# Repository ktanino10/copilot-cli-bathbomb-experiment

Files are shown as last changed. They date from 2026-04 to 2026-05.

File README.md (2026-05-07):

# 🛁🐱 copilot-cli-bathbomb-experiment

**[日本語](#日本語) | [English](#english)**

---

## 日本語

🧪 GitHub Copilot CLIで画像からバスボム用3Dプリント型（モールド）を自動生成する実験記録

### 概要

GitHub のロゴ（Octocat）の画像から、猫型バスボム用の3Dプリント型を自動生成します。
2分割のクラムシェル（貝殻型）構造で、乾燥後に左右にパカッと開いてバスボムを取り出せます。

### 生成される型

猫シルエットの **クラムシェル2分割型**（左右ハーフ：A・B）

- 左右ハーフが鏡像でパーティングプレーン上で合わさる
- 抜き勾配 **8°**（v1の5°から増、粉末材料での離型性を改善）
- フィレット R3mm（角を丸めてひび割れ防止）
- 壁厚 4mm・床厚 4mm
- 外周フランジ 5mm 幅（ゴムバンドで圧着するためのリム）
- φ4mm 位置決めピン × 4 本（ハーフAにピン、ハーフBに穴）
- 目標サイズ：おおむね 80×80×20mm の手のひらサイズバスボム

### 過去の試作（参考）

第1回試作の片面コンテナ型 (`mold_cat_container.stl` / `mold_cat_container_mirrored.stl`) は履歴として残しています。失敗の経緯は [`experiments/2026-05-04-trial-01/`](experiments/2026-05-04-trial-01/) を参照。

### 🎉 成功事例（Trial 02）

第2回試作で **4色のOctocat バスボム作りに成功** しました 🐱✨
GitHub を退職する同僚（元 Microsoft 社員）への餞別ギフトとして、Microsoft ロゴカラー（赤・緑・青・黄）の 4 色 Octocat バスボムを製作し、**Lush で買った期間限定の「マリオはてなブロック」型ギフトボックス**に詰めて贈りました（ついでに同店で「ヨッシーの卵」バスボム＋泡ボムも購入し、保険として同梱）。

ちなみに今回は v2 自動生成クラムシェルを **使わず**、v1 のコンテナ型を **Bambu Studio で左右 2 分割** にカットして印刷した workaround で離型問題を解決しています。

| 離型成功 | 4 色セット完成 |
|---|---|
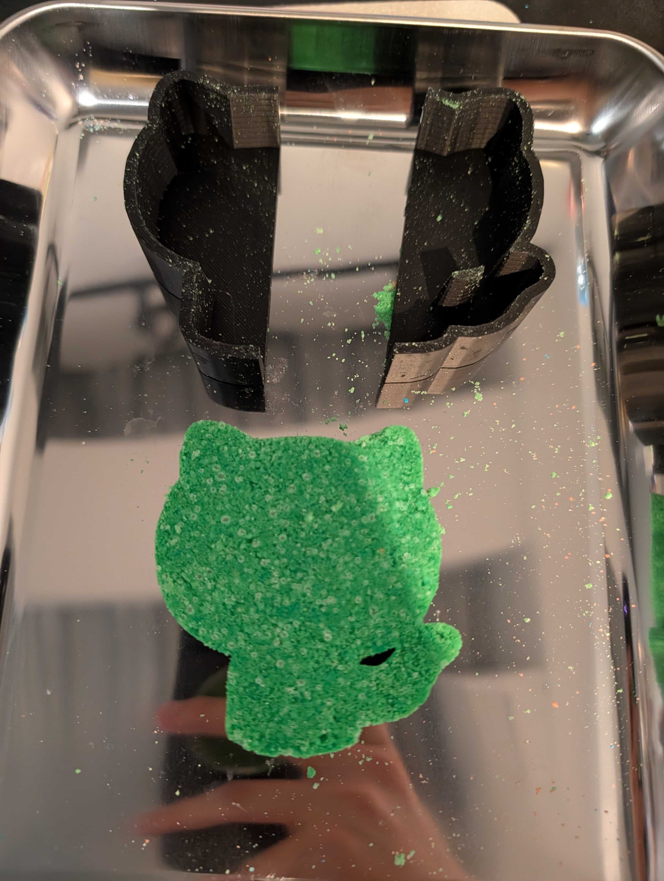
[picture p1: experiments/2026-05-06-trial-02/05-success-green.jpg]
成功した緑バスボム
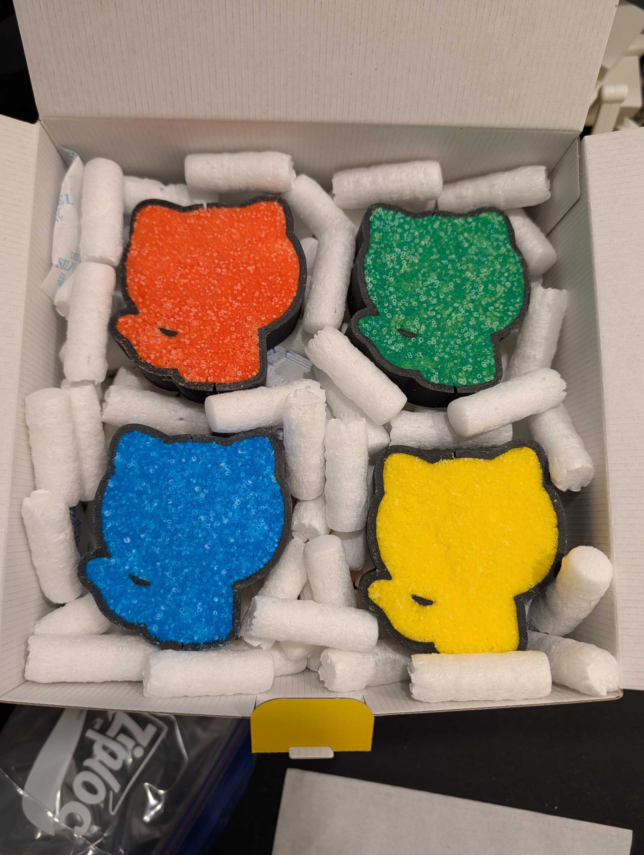
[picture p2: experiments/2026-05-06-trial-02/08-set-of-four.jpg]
4色Octocatバスボム
|  |  |

詳しい製作工程・レシピ・写真・動画・学びは [`experiments/2026-05-06-trial-02/`](experiments/2026-05-06-trial-02/) を参照。

> 📘 **離型ガイド (GitHub Pages)**: 完成したバスボムを型から崩さずに取り出すコツを
> Codelab 形式でまとめています →
> **<https://ktanino10.github.io/copilot-cli-bathbomb-experiment/>**
> （8 ステップ・約 14 分。NG 動作／推奨手順／"そもそも完全に外さない" 運用 ほか）
> 🌐 **日本語 / English** 両対応 — 右上のセレクターで切り替え可
> ([🇯🇵 JA](https://ktanino10.github.io/copilot-cli-bathbomb-experiment/?version=v1.0.0&lang=ja) ·
>  [🇬🇧 EN](https://ktanino10.github.io/copilot-cli-bathbomb-experiment/?version=v1.0.0&lang=en))

### 使い方

```bash
# 依存ライブラリのインストール
pip install pillow numpy scipy scikit-image shapely trimesh manifold3d

# STLファイル生成
python generate_mold.py
```

### 出力ファイル

```
mold_cat_clamshell_A.stl  — クラムシェル ハーフA（位置決めピン付き）
mold_cat_clamshell_B.stl  — クラムシェル ハーフB（ピン穴付き）
```

両方を1部ずつプリントして1セットになります。

### 📸 STL プレビュー

> ⚠️ **GitHub の STL 3D ビューアが「Unable to render code block」と表示されることがあります。**
> 形を確認するための静的プレビュー画像を `previews/` に同梱しています。
> 詳細にスクスクと回したい場合は、STL を [Raw でダウンロード](https://raw.githubusercontent.com/ktanino10/copilot-cli-bathbomb-experiment/main/mold_cat_clamshell_A.stl) して
> [ViewSTL](https://www.viewstl.com/) などのオンラインビューアで開くか、Bambu Studio などローカルツールでご覧ください。

| クラムシェル A（v2、ピン付き） | クラムシェル B（v2、穴付き） |
|---|---|
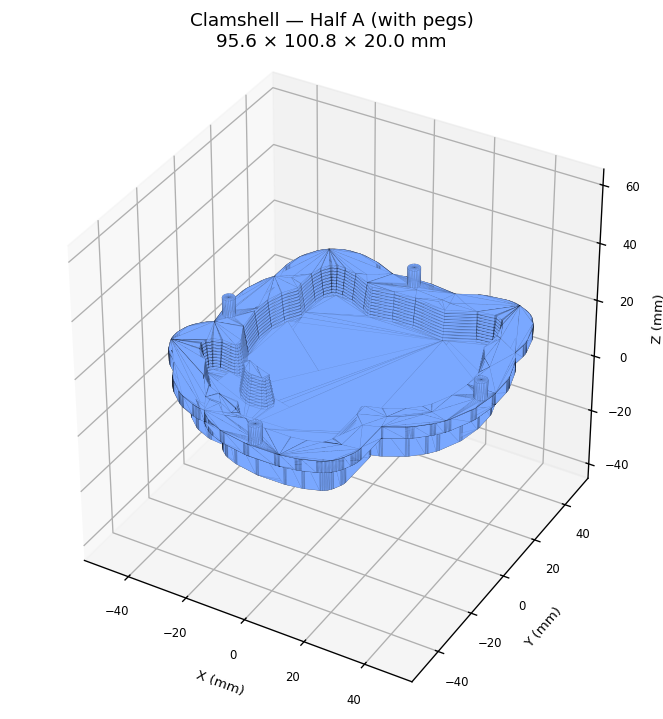
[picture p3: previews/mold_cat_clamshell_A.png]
Half A preview
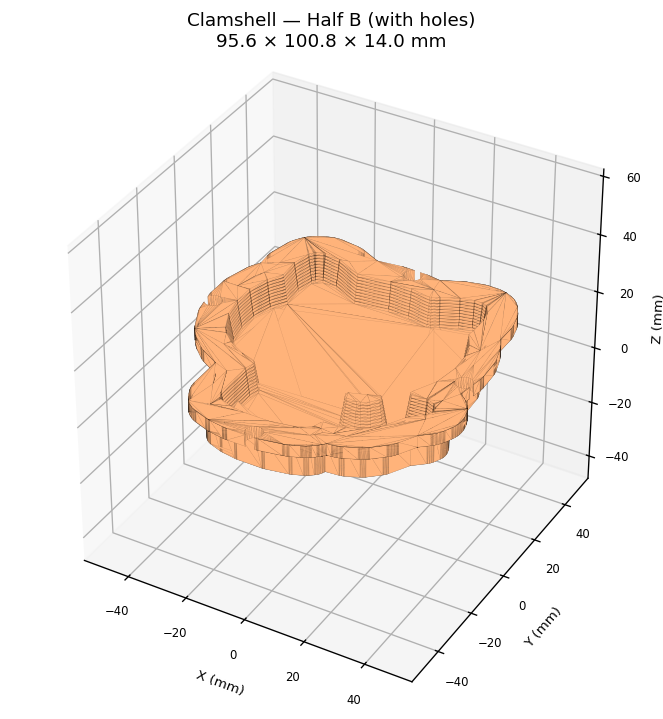
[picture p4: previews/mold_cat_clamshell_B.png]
Half B preview
|  |  |

| v1 コンテナ型（参考） | v1 コンテナ型・ミラー（参考） |
|---|---|
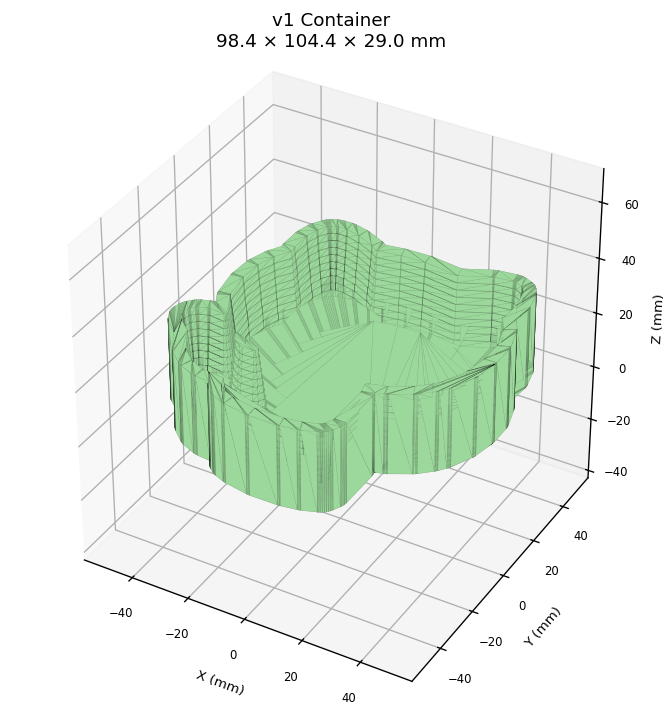
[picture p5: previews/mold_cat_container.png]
v1 preview
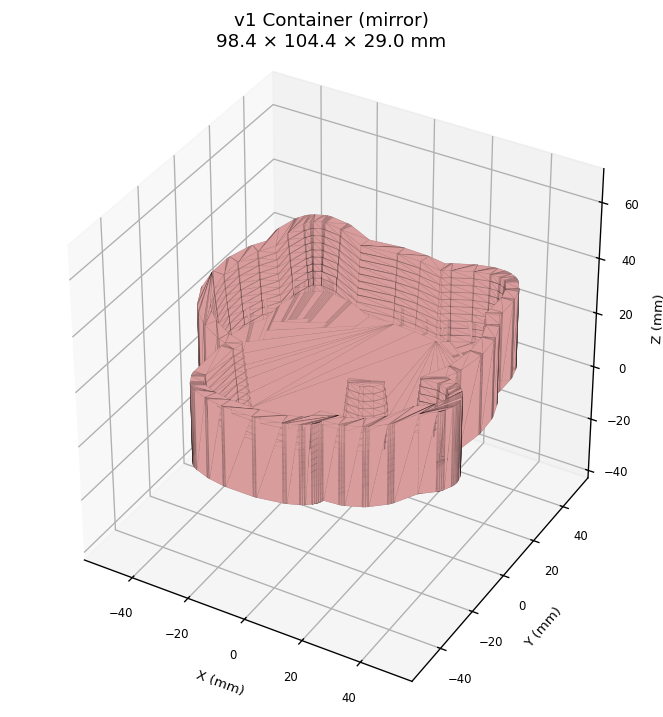
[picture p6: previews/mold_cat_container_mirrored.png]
v1 mirrored preview
|  |  |

これらの PNG は `python generate_previews.py` で再生成できます（trimesh + matplotlib）。

### 3Dプリント推奨設定

| パラメータ | 設定値 |
|---|---|
| プリンター | FDM |
| フィラメント | PLA |
| レイヤー高さ | 0.2mm |
| インフィル | 20〜30% |
| サポート | なし |
| ブリム | あり（反り防止） |

印刷後はキャビティ内面をサンドペーパー（#400→#800）で研磨し、使用時は食品用ラップを敷いてください。

### 型の設計仕様

| 項目 | 値 |
|---|-----|
| 構造 | クラムシェル2分割（左右ハーフ） |
| キャビティ深さ | 10mm × 2（合計約20mm） |
| 猫シルエット幅 | 約80mm |
| 壁厚 | 4mm |
| 床厚 | 4mm |
| 抜き勾配 | 8° |
| フィレット | R3mm |
| フランジ幅 / 厚さ | 5mm / 4mm |
| 位置決めピン | φ4mm × 4本（A：ピン／B：穴） |

### 制作ガイド

📖 **[GUIDE.md](GUIDE.md)** — 買い出しリスト・全手順・トラブルシューティング（日本語）

📖 **[GUIDE_EN.md](GUIDE_EN.md)** — Full guide in English

### ツール

- [GitHub Copilot CLI](https://githubnext.com/projects/copilot-cli/)
- Python 3 + trimesh + manifold3d（3Dブーリアン演算）
- scikit-image + shapely（画像→ポリゴン変換）

---

## English

🧪 Experiment: Auto-generating 3D-printable bath bomb molds from images with GitHub Copilot CLI

### Overview

Automatically generates a 3D-printable bath bomb mold in the shape of the GitHub Octocat,
designed as a **two-piece clamshell** so the finished bath bomb pops out cleanly when the
two halves are unclipped after drying.

### Generated Mold

Two-piece **clamshell** mold (halves A and B):

- Mirrored halves meeting on a flat parting plane
- **8° draft angle** (steeper than v1's 5° — much easier release for powdery material)
- R3mm fillets on the cat silhouette (prevents cracking)
- 4mm walls and 4mm floor on each half
- 5mm outer flange around the parting plane (for rubber-band clamping)
- 4 × φ4mm alignment dowels (pegs on side A, matching holes on side B)
- Target bath bomb size ≈ 80×80×20mm — fits in one hand

### Previous Trial (kept for reference)

The original single-sided container mold (`mold_cat_container.stl` /
`mold_cat_container_mirrored.stl`) is kept in the repo as historical artifact.
See [`experiments/2026-05-04-trial-01/`](experiments/2026-05-04-trial-01/) for what went wrong.

### 🎉 Success Story (Trial 02)

The second trial **produced four Octocat bath bombs successfully** 🐱✨
They were made as a farewell gift for a colleague leaving GitHub (formerly at Microsoft) — cast in
the **Microsoft logo colors (red, green, blue, yellow)** and packed into a
**Mario "question-block" gift box bought at Lush as a limited-edition item**
(a Lush "Yoshi's Egg" bath bomb and a foam bomb were picked up at the same store
and included as backup gifts).

Note that this batch did **not** use the v2 auto-generated clamshell; instead the v1 container
mold was **split left/right in Bambu Studio's slicer** before printing — a workaround that
solved the demolding problem with no model redesign.

| Clean release | Four-color set |
|---|---|
| Successful green Octocat | Four Octocat bath bombs |

See [`experiments/2026-05-06-trial-02/`](experiments/2026-05-06-trial-02/) for the full
process, recipe, photos, video and lessons learned.

> 📘 **Demolding Guide (GitHub Pages)**: a Codelab-style walkthrough of how to
> safely release the finished bath bomb from its mold →
> **<https://ktanino10.github.io/copilot-cli-bathbomb-experiment/>**
> (8 steps · ~14 min · do's and don'ts, the recommended one-half release,
> and the "don't fully demold at all" gifting pattern).
> 🌐 **Available in 日本語 / English** — toggle in the top-right
> ([🇬🇧 EN](https://ktanino10.github.io/copilot-cli-bathbomb-experiment/?version=v1.0.0&lang=en) ·
>  [🇯🇵 JA](https://ktanino10.github.io/copilot-cli-bathbomb-experiment/?version=v1.0.0&lang=ja))

### Usage

```bash
# Install dependencies
pip install pillow numpy scipy scikit-image shapely trimesh manifold3d

# Generate STL
python generate_mold.py
```

### Output

```
mold_cat_clamshell_A.stl  — Clamshell half A (with alignment pegs)
mold_cat_clamshell_B.stl  — Clamshell half B (with matching holes)
```

Print one of each to make a complete set.

### 📸 STL Previews

> ⚠️ **GitHub's inline STL 3D viewer sometimes shows "Unable to render code block".**
> Static PNG previews are included in `previews/` so you can see the geometry
> without the viewer. For an interactive look, download the raw STL and open it
> in [ViewSTL](https://www.viewstl.com/) or a local tool like Bambu Studio /
> PrusaSlicer / MeshLab.

| Clamshell A (v2, with pegs) | Clamshell B (v2, with holes) |
|---|---|
| Half A preview | Half B preview |

| v1 container (reference) | v1 container, mirrored (reference) |
|---|---|
| v1 preview | v1 mirrored preview |

These PNGs are regenerated by `python generate_previews.py` (trimesh + matplotlib).

### Recommended Print Settings

| Parameter | Value |
|---|---|
| Printer | FDM |
| Filament | PLA |
| Layer height | 0.2mm |
| Infill | 20–30% |
| Support | None |
| Brim | Yes (prevents warping) |

Sand the cavity interior (#400 → #800 grit) after printing. Line with plastic wrap before use.

### Mold Specs

| Spec | Value |
|---|---|
| Structure | Two-piece clamshell (halves A + B) |
| Cavity depth | 10mm × 2 (≈20mm total bath bomb) |
| Cat silhouette width | ≈80mm |
| Wall thickness | 4mm |
| Floor thickness | 4mm |
| Draft angle | 8° |
| Fillet radius | R3mm |
| Flange width / thickness | 5mm / 4mm |
| Alignment dowels | 4 × φ4mm (pegs on A, holes on B) |

### Crafting Guide

📖 **[GUIDE.md](GUIDE.md)** — Full guide in Japanese (日本語)

📖 **[GUIDE_EN.md](GUIDE_EN.md)** — Shopping list, step-by-step instructions & troubleshooting

### Tools

- [GitHub Copilot CLI](https://githubnext.com/projects/copilot-cli/)
- Python 3 + trimesh + manifold3d (3D boolean operations)
- scikit-image + shapely (image → polygon conversion)

## License

MIT

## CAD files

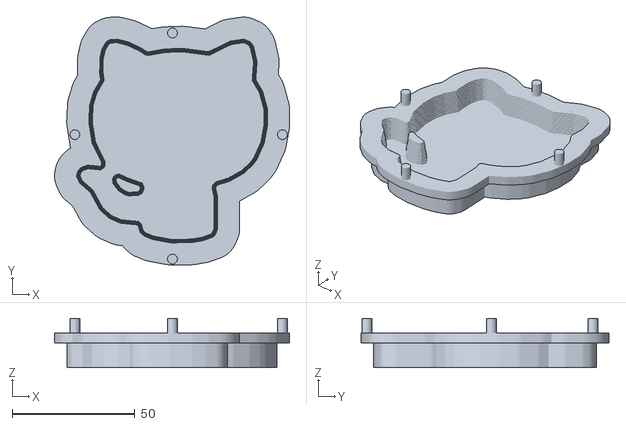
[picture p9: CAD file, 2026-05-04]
mold_cat_clamshell_A.stl
95.6 x 100.8 x 20.0

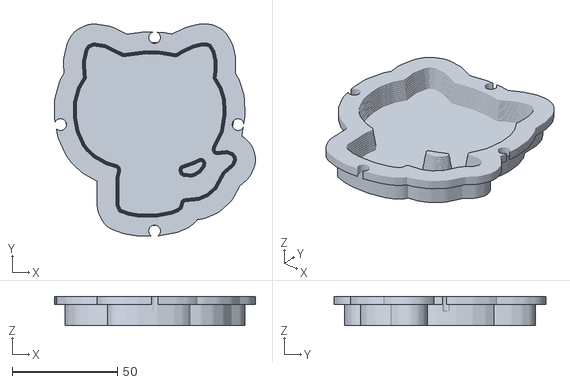
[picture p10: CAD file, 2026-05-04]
mold_cat_clamshell_B.stl
95.6 x 100.8 x 14.0

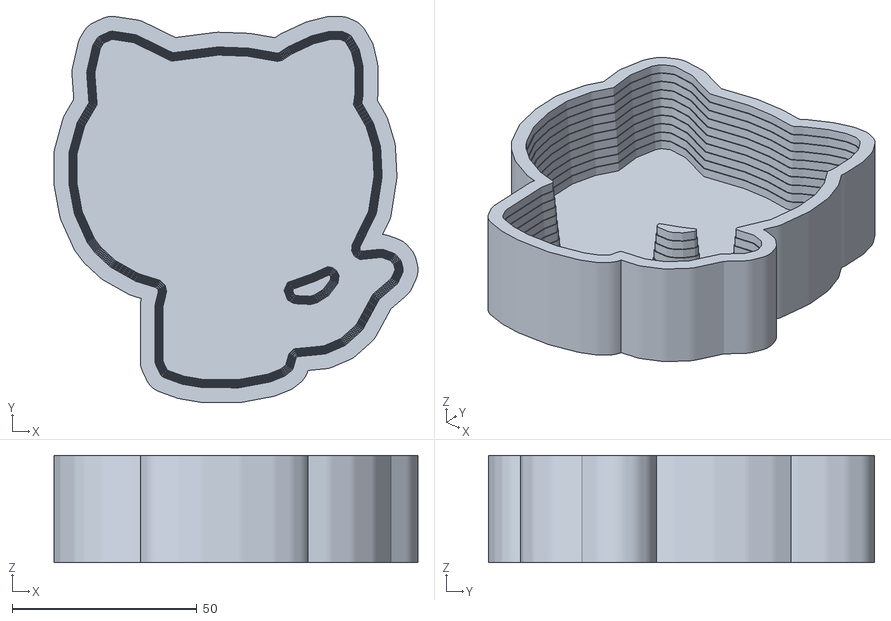
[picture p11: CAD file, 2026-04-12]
mold_cat_container_mirrored.stl
98.4 x 104.4 x 29.0

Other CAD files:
mold_cat_container.stl

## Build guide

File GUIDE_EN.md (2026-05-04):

# 🛁🐱 GitHub Octocat Bath Bomb — Complete Crafting Guide

A black, lavender-scented bath bomb shaped like the GitHub Octocat.
The **two-piece clamshell mold** holds the shape firmly while it cures, then
opens like a shell so the bath bomb pops out cleanly.

---

## 📋 Shopping List

### 🛒 Grocery / Dollar Store
| # | Item | Purpose | Notes |
|---|---|---|---|
| 1 | Baking soda (food grade) | Main ingredient | 200g+ |
| 2 | Citric acid | Fizzing agent | 100g+ |
| 3 | Cornstarch | Binding agent | 50g |
| 4 | Small spray bottle | For spraying rubbing alcohol | ~50ml |
| 5 | Rubber gloves | Prevent charcoal stains | Disposable |
| 6 | Thick rubber bands or hair ties | Clamp the two halves together | 2–3 pieces |
| 7 | Clear gift bags | Gift wrapping | With ribbon if possible |

### 💊 Pharmacy / Drugstore
| # | Item | Purpose | Notes |
|---|---|---|---|
| 8 | Isopropyl alcohol (91%+) or witch hazel | Moistening agent (water substitute) | ~$5. Water triggers fizzing — must use alcohol! |

### 🛍 Grocery Store
| # | Item | Purpose | Notes |
|---|---|---|---|
| 9 | Coconut oil or olive oil | Moisturizer / binder | 1–2 tbsp needed |

### 📦 Online (order in advance)
| # | Item | Purpose | Notes |
|---|---|---|---|
| 10 | Lavender essential oil | Fragrance | 10ml bottle |
| 11 | Activated charcoal powder (food grade) | Black color | 1–2 tsp needed |

### 🏠 Already at Home (check)
| Item | Purpose |
|---|---|
| Large bowl | Mixing |
| Measuring spoons / kitchen scale | Measuring |
| Plastic wrap or cooking oil (release agent) | Line / coat the cavity for easy demold |
| Parchment paper | Drying surface |
| Spatula or ruler | Smooth the surface |
| Sandpaper #400, #800 | Smooth the 3D-printed mold interior |

### 💰 Estimated Budget: $15–30

---

## 🗓 Schedule Overview

| Phase | Task | Time |
|---|---|---|
| **A. 3D Print** | Print one of each STL (halves A and B) | 2–3 hours |
| **B. Shopping** | Buy materials (parallel with A) | — |
| **C. Mold Prep** | Sand interior + flatten flange | 20 min |
| **D. Crafting** | Mix → fill halves → close clamshell | 1–1.5 hours |
| **E. Drying** | Let sit clamped | 24–48 hours |
| **F. Finishing** | Open clamshell → demold → wrap | 30 min |

---

## 🔧 Phase A: 3D Printing

### Slicer Settings (Cura, etc.)
| Parameter | Value |
|---|---|
| Files | `mold_cat_clamshell_A.stl` + `mold_cat_clamshell_B.stl` |
| Filament | PLA |
| Layer height | 0.2mm |
| Infill | 20–30% |
| Wall thickness | 1.2mm (3 walls) |
| Support | **None** |
| Brim | **Yes** (prevents warping) |
| Nozzle temp | 200–210°C |
| Bed temp | 60°C |

💡 **Print orientation tip**: Print each half with the **flange face up** (cavity-back side on the bed). This keeps the pin/hole geometry crisp and the flange flat for a tight seal.

### After Printing
1. Remove brim with a knife
2. Sand the cavity interior:
   - **#400 grit** → remove layer lines
   - **#800 grit** → smooth finish
3. Lightly sand the **flange face** with #400 to ensure it's perfectly flat (better seal)
4. Test-fit the two halves: pegs should slide into holes with a snug press fit

---

## 🧪 Phase D: Making the Bath Bomb

### D-1. Mix Dry Ingredients
```
Add to bowl in order:
  ① Baking soda       200g
  ② Citric acid        100g
  ③ Cornstarch          50g
  ④ Charcoal powder     1–2 tsp (start small!)
```
- Wear rubber gloves! (charcoal stains are hard to remove)
- Mix thoroughly with a fork, breaking up any clumps (2–3 min)

### D-2. Add Wet Ingredients
```
  ⑤ Coconut oil        1–2 tbsp (melt in microwave if solid)
  ⑥ Lavender EO        10–15 drops
```
- Mix well

### D-3. Adjust Moisture
```
  ⑦ Pour rubbing alcohol into spray bottle
    → Spritz 1–2 pumps at a time while mixing
```
- 🎯 **Target consistency**: Holds shape when squeezed, crumbles when lightly pressed
  - Like "wet sand" texture
  - Too crumbly → one more spritz
  - Too wet → add a little baking soda

- ⚠️ **NEVER use water!** It triggers the fizzing reaction

### D-4. Fill the Clamshell Mold

```
   Half A (pin side)         Half B (hole side)
   ┌─────────────────┐       ┌─────────────────┐
   │  ① Coat cavity   │       │  ① Coat cavity   │   ← thin smear of oil
   │     with oil     │       │     with oil     │     (or line with wrap)
   │                  │       │                  │
   │  ② Heap mixture  │       │  ② Heap mixture  │   ← slightly above
   │     in cavity ↑↑↑│       │     in cavity ↑↑↑│     the cavity rim
   │                  │       │                  │
   │  ③ Pack firmly   │       │  ③ Pack firmly   │
   └─────────────────┘       └─────────────────┘
                  ↓ clamp ↓
            ┌─────────────────┐
            │ Press the two    │  ← align pins into holes
            │ halves together  │     and push straight down
            │ (the heaped mix  │
            │  compresses for  │
            │  a tight bond)   │
            └─────────────────┘
                  ↓ secure ↓
            ┌─────────────────┐
            │  ④ Wrap rubber   │  ← cross-pattern (X) over
            │     bands tightly│     the flange
            └─────────────────┘
```

#### Detailed Steps:
1. **Coat the cavity**: Smear a thin layer of cooking oil (or coconut oil) on the interior of each half with a finger or paper towel. (Better than plastic wrap for a clamshell — wrap tends to wrinkle in this geometry.)
2. **Fill both halves**: Divide the mixture roughly in half and **heap it slightly above the rim** of each cavity (the excess will compress when you close the clamshell).
3. **Pack firmly**: Press the mixture in each half with your fingertips.
4. **Close the clamshell**: Place half B (holes) onto half A (pins), aligning the pegs into the holes. Press straight down firmly until the flanges meet.
5. **Clamp with rubber bands**: Wrap rubber bands across the flange in an X pattern (one vertical, one horizontal). They must be tight — slack means a gap and a visible seam.

---

## ⏳ Phase E: Drying

1. Leave the clamped clamshell on parchment paper
2. Place in a **well-ventilated area** for **24–48 hours**
3. ⚠️ **Don't touch it!** It's extremely fragile while drying
4. ⚠️ Avoid humid areas (bathroom, kitchen)
5. Summer: 24 hours. Winter: 48 hours.

---

## 🎁 Phase F: Finishing & Wrapping

### Opening the Clamshell
1. Carefully remove the rubber bands
2. Hold the flange with both hands and **gently pull the two halves apart** sideways (like opening a clam)
3. The bath bomb usually stays in one half — flip that half over and **let it drop into your palm**
4. If it sticks, **tap the back of the half lightly** with your other hand
5. ⚠️ Be gentle — ears and tentacle are fragile

### Touch-up
- A faint flash line may appear along the parting plane — smooth it with a finger
- If a corner chipped, press leftover mixture onto it to repair

### Gift Wrapping
1. Wrap the bath bomb tightly in plastic wrap (moisture barrier)
2. Place in a clear gift bag with a ribbon
3. Include a usage card (see below)

### Usage Card (to include with gift)
```
┌──────────────────────────────────────┐
│  🛁 GitHub Octocat Bath Bomb         │
│                                      │
│  Drop into a warm bath (38–40°C)     │
│  and watch it fizz, releasing        │
│  a relaxing lavender scent.          │
│                                      │
│  ⚠️ The water will turn dark —       │
│  activated charcoal is natural       │
│  and gentle on skin.                 │
│                                      │
│  🌿 Enjoy the lavender scent!        │
└──────────────────────────────────────┘
```

---

## ⚠️ Troubleshooting

| Problem | Cause | Fix |
|---|---|-----|
| Won't hold shape / crumbly | Not enough alcohol | Add 1–2 more spritzes |
| Started fizzing during mixing | Water got in | Mold quickly. Next time use only alcohol |
| Won't release from cavity | Forgot release agent / packed too tight | Always coat with oil. Try 30 min in freezer |
| Clamshell won't close | Too much mixture in the halves | Heap less — just enough to compress on close |
| Visible seam / gap at parting line | Rubber bands too loose | Use stronger bands in a tight X pattern |
| Ears broke off | Thin sections are fragile | Repair with leftover mixture. Pack thicker next time |
| Cracked while drying | Dried too fast / uneven thickness | Move to a less drafty spot; the closed mold dries it slowly which is good |
| Water turned pitch black | Too much charcoal | Use ½ tsp next time |
| Bathtub stained | Charcoal / food coloring | Clean with melamine sponge. Charcoal stains less |

---

## 💡 Tips for Success

1. **Practice first**: Make a small round bath bomb by hand to get the feel
2. **Charcoal — less is more**: ½ tsp is enough for deep black. Too much = pitch-black bath water
3. **Release agent — go thin**: Too much oil makes the bath bomb surface greasy
4. **Pack firmly**: Harder than you think. Weak packing = crumbling
5. **Alcohol — go slow**: Too little is better than too much
6. **Store sealed**: Keep finished bath bomb away from moisture. Gift within 1–2 weeks

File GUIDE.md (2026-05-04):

# 🛁🐱 GitHub Octocat バスボム — 完全制作ガイド

黒色・ラベンダーの香り付きの猫型バスボム。
**クラムシェル2分割型**でしっかりした形を成形し、乾燥後はパカッと開いて取り出します。

---

## 📋 買い出しリスト

### 🛒 100均（ダイソー・セリア等）
| # | 商品 | 用途 | 備考 |
|---|---|---|---|
| 1 | 重曹（食用グレード） | バスボム主成分 | 200g以上。掃除用でも可だが食用が肌に優しい |
| 2 | クエン酸 | 発泡剤 | 100g以上 |
| 3 | 片栗粉 or コーンスターチ | 固め剤 | 50g |
| 4 | スプレーボトル（小） | エタノール噴霧用 | 50ml程度 |
| 5 | ゴム手袋 | 竹炭で手が汚れるのを防止 | 使い捨てタイプ |
| 6 | 輪ゴム（太め）or ヘアゴム | 型を圧着するため | 2〜3本 |
| 7 | ラッピング袋（透明） | ギフト包装 | リボン付きだと便利 |

### 💊 ドラッグストア
| # | 商品 | 用途 | 備考 |
|---|---|---|---|
| 8 | 無水エタノール | 湿らせ用（水の代替） | ¥400〜600。水だと発泡が始まるため必須 |

### 🛍 スーパー
| # | 商品 | 用途 | 備考 |
|---|---|---|---|
| 10 | ココナッツオイル or オリーブオイル | 保湿・バインダー | 大さじ1〜2。小さいサイズでOK |

### 📦 Amazon（事前注文推奨）
| # | 商品 | 用途 | 備考 |
|---|---|---|---|
| 8 | ラベンダーエッセンシャルオイル | 香り付け | 10ml。無印良品でも可 |
| 9 | 竹炭パウダー（食用グレード） | 黒色着色 | 小さじ1〜2使用。100g入りで¥300〜500 |

### 🏠 自宅にあるもの（確認）
| 商品 | 用途 |
|---|---|
| ボウル（大） | 材料の混合 |
| 計量スプーン・キッチンスケール | 計量 |
| 食品用ラップ or サラダ油（離型剤） | キャビティ内面の離型用 |
| クッキングシート | 乾燥時の下敷き |
| ヘラ or 定規 | 表面をならす |
| サンドペーパー #400, #800 | 3Dプリント型の内面研磨 |

### 💰 予算目安: ¥2,000〜3,500

---

## 🗓 全体スケジュール

| フェーズ | 作業 | 所要時間 |
|---|---|---|
| **A. 3Dプリント** | STL（ハーフA・B 各1個）をスライサーで読み込み→印刷 | 2〜3時間 |
| **B. 買い出し** | 上記リストの材料購入（Aと並行） | — |
| **C. 型の後処理** | サンドペーパーで内面研磨・フランジ平面化 | 20分 |
| **D. バスボム制作** | 混合→ハーフに詰める→クラムシェルを閉じる | 1〜1.5時間 |
| **E. 乾燥** | 圧着したまま放置 | 24〜48時間 |
| **F. 仕上げ** | 開封→取り出し→ラッピング | 30分 |

---

## 🔧 フェーズA: 3Dプリント

### スライサー設定（Cura等）
| パラメータ | 設定値 |
|---|---|
| ファイル | `mold_cat_clamshell_A.stl` ＋ `mold_cat_clamshell_B.stl` |
| フィラメント | PLA |
| レイヤー高さ | 0.2mm |
| インフィル | 20〜30% |
| 壁の厚さ | 1.2mm（3周） |
| サポート | **なし** |
| ブリム | **あり**（反り防止） |
| 印刷温度 | 200〜210℃ |
| ベッド温度 | 60℃ |

💡 **配置のコツ**: 各ハーフは**フランジ面を上に向けて**プリントすると、ピン/穴の精度が出やすく、フランジ平面も綺麗になります（ベッド側は曲面のないキャビティ背面側）。

### 印刷後
1. ブリムをカッターで除去
2. 内面（キャビティ）をサンドペーパーで研磨
   - **#400** → 積層跡を除去
   - **#800** → 滑らかに仕上げ
3. **フランジ平面**は#400で軽く撫でて平らにする（接合精度UP）
4. ハーフAのピンとハーフBの穴を実際に合わせて、スッと嵌まることを確認

---

## 🧪 フェーズD: バスボム制作

### D-1. 粉末材料を混ぜる
```
ボウルに入れる順番:
  ① 重曹         200g
  ② クエン酸      100g
  ③ コーンスターチ  50g
  ④ 竹炭パウダー   小さじ1〜2（少量から！）
```
- ゴム手袋を着用！（竹炭は手につくと落ちにくい）
- フォークでダマをつぶしながらよく混ぜる（2〜3分）

### D-2. 液体材料を加える
```
  ⑤ ココナッツオイル   大さじ1〜2（固形の場合はレンジで溶かす）
  ⑥ ラベンダーEO      10〜15滴
```
- よく混ぜる

### D-3. 湿度を調整する
```
  ⑦ 無水エタノールをスプレーボトルに入れる
    → 混合物に「シュッ、シュッ」と1〜2回ずつ吹きかけながら混ぜる
```
- 🎯 **完成の目安**: ギュッと握ると固まり、軽く押すと崩れる状態
  - 「湿った砂」のような質感
  - ポロポロすぎる → もう1プッシュ
  - ベチャベチャ → 入れすぎ！重曹を少し追加

- ⚠️ **絶対に水を使わない！** 水だとシュワシュワ反応が始まってしまう

### D-4. クラムシェル型に詰める

```
   ハーフA（ピン側）         ハーフB（穴側）
   ┌─────────────────┐      ┌─────────────────┐
   │  ① 内面に離型処理 │      │  ① 内面に離型処理 │   ← サラダ油を薄塗り or ラップ
   │                  │      │                  │
   │  ② 山盛りに材料を │      │  ② 山盛りに材料を │   ← キャビティが少し
   │     詰める ↑↑↑   │      │     詰める ↑↑↑   │     はみ出るくらい
   │                  │      │                  │
   │  ③ ギュッと押し  │      │  ③ ギュッと押し  │
   │     固める       │      │     固める       │
   └─────────────────┘      └─────────────────┘
                  ↓ 合わせる ↓
            ┌─────────────────┐
            │   両ハーフを合体  │   ← ピンを穴に差し込みながら
            │     ピン → 穴    │     ぐっと押し付ける
            │   (はみ出した分が │
            │    つぶれて密着)  │
            └─────────────────┘
                  ↓ 圧着 ↓
            ┌─────────────────┐
            │  ④ 輪ゴムで       │   ← 縦・横にX字にかける
            │     しっかり固定  │     (フランジ部分で押さえる)
            └─────────────────┘
```

#### 詳細手順:
1. **離型処理**: 各ハーフのキャビティ内面に、サラダ油 or ココナッツオイルを薄く塗る（指 or キッチンペーパーで）。ラップを敷くより推奨（クラムシェルだとラップは逆にしわが入りやすい）
2. **両ハーフに材料を詰める**: 半量ずつ、各ハーフのキャビティに **少し山盛り** に詰める（キャビティ容量の少し多め＝合体時に圧縮される分の余裕）
3. **ギュッと押し固める**: 各ハーフ内で指の腹でしっかり圧縮
4. **ハーフA（ピン側）の上にハーフBをかぶせる**: ピンと穴を合わせながらまっすぐ降ろし、ぐっと押し付ける。フランジ同士がぴったり合うまで
5. **輪ゴムで圧着**: フランジ部分にX字（縦＋横）に輪ゴムをかけて固定。緩いと隙間ができるので、しっかり締める

---

## ⏳ フェーズE: 乾燥

1. クラムシェルを輪ゴムで圧着したまま、クッキングシートの上に置く
2. **風通しの良い場所**で **24〜48時間** 放置
3. ⚠️ **触らない！** 乾燥中は非常にもろい
4. ⚠️ 湿気の多い場所（風呂場・キッチン）は避ける
5. 夏場は24時間、冬場は48時間が目安

---

## 🎁 フェーズF: 仕上げ・ラッピング

### 型から取り出す（クラムシェル開封）
1. 輪ゴムをそっと外す
2. 型のフランジ部分を両手で持ち、**左右にゆっくり開く**（パカッと貝殻のように）
3. バスボムは通常どちらか片方のハーフに残るので、ハーフをひっくり返して**手のひらに優しく落とす**
4. もし張り付いて落ちない場合：ハーフの背面（キャビティの裏側）を反対の手で軽くトントンと叩く
5. ⚠️ 力を入れすぎない（耳や触手が折れやすい）

### 仕上げ
- パーティング面（合わせ目）に薄くバリが出ることがあるので、指で軽く撫でて整える
- 角が欠けた場合は、余った混合物を指で押し付けて補修

### ラッピング
1. バスボムをラップでぴったり包む（湿気防止）
2. 透明袋に入れてリボンで結ぶ
3. 使い方カードを添える（下記参照）

### 使い方カード（同封用）
```
┌─────────────────────────────────┐
│  🛁 GitHub Octocat バスボム      │
│                                  │
│  お湯（38〜40℃）を張った浴槽に   │
│  入れてください。                 │
│  シュワシュワと溶けて、ラベンダー │
│  の香りが広がります。             │
│                                  │
│  ⚠️ お湯が黒くなりますが         │
│  竹炭は天然素材で肌に優しいです。 │
│  気になる場合は早めにお湯を       │
│  抜いてください。                 │
│                                  │
│  🌿 ラベンダーの香りで            │
│  リラックスタイムを♪             │
└─────────────────────────────────┘
```

---

## ⚠️ トラブルシューティング

| 問題 | 原因 | 対策 |
|---|---|---|
| 固まらない・ポロポロ | エタノール不足 | もう1〜2プッシュ追加 |
| シュワシュワし始めた | 水分が入った | 素早く型に詰める。次回はエタノールのみ使用 |
| 型から出ない | 離型剤を塗り忘れた / 圧縮しすぎ | 油を必ず薄塗り。冷凍庫30分→再挑戦 |
| クラムシェルが閉じない | 材料を詰めすぎ | 詰める量を減らす（少し山盛り＝合体で圧縮される程度） |
| 合わせ目に隙間ができる | 輪ゴムが緩い | より強い輪ゴムでX字にしっかり固定 |
| 耳が折れた | 薄い部分は壊れやすい | 余った材料で指で補修。次回は少し厚めに |
| 乾燥中にひび割れ | 乾燥が速すぎる / 厚みが不均一 | 乾燥場所を変える。型を密閉した状態でゆっくり乾燥 |
| お湯が真っ黒 | 竹炭パウダー入れすぎ | 次回は小さじ1/2から調整 |
| 浴槽に色が残った | 竹炭 or 食用色素 | メラミンスポンジで落ちる。竹炭の方が残りにくい |

---

## 💡 成功のコツ

1. **初回は練習**: 余った材料で丸いミニバスボム（手で丸める）を1個作って感覚をつかむ
2. **竹炭は少量から**: 小さじ1/2で十分黒くなる。多すぎるとお湯が真っ黒に
3. **離型剤は薄く**: 油を塗りすぎるとバスボムの表面がベタつく
4. **押し固める力加減**: 思ったより強めにギュッと。弱いと崩れる
5. **エタノールは少しずつ**: 入れすぎより入れなさすぎの方がマシ
6. **保管は密閉**: 完成品は湿気を避け、1〜2週間以内にプレゼントする

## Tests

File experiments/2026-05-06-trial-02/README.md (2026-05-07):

# 🎉 Trial 02 — 2026-05-06（成功）

**[日本語](#日本語) | [English](#english)**

---

## 日本語

第2回試作の記録。**4色のOctocatバスボム作りに成功** 🐱✨

[第1回 (失敗)](../2026-05-04-trial-01/) で得た学びを反映しつつ、**実際は別アプローチ**で離型問題を解決しました（後述）。

> 📌 **ただし注意**: 離型自体は成功したものの、Octocat の細い耳・触手部分が脆く、
> 人に手渡す際の振動・衝撃で崩れやすいことが判明。最終的なギフトは
> **「型に詰めたまま」渡す方針に変更**しました。受取人がクラムシェルを開けて、
> バスボムをそのままお湯に投入する形に。3D プリント型もギフトの一部です 🎁

---

### 背景ストーリー 🎁

GitHub を退職する同僚（**元 Microsoft 社員**）への餞別ギフトとして製作。
Octocat の形をした **Microsoft ロゴカラー（赤・緑・青・黄）** の 4 色バスボムを作り、
**Lush で見つけた期間限定の「マリオはてなブロック」型ギフトボックス**に詰めて
贈ることに。

> 💡 ギフト箱を買いに **Lush** に立ち寄った際、ついでに「ヨッシーの卵」バスボムと
> 泡ボムも 1 個ずつ購入。「万が一手作りが失敗しても恥をかかないように」という
> 保険として同梱しました。結果的に手作りも成功したので、両方とも贈ることに。

---

### 使用した型 — 設計と現実

このリポジトリには 2 種類の型 STL があります:

| 型 | ファイル | 状態 |
|---|---|---|
| v1: 片面コンテナ型 | [`mold_cat_container.stl`](../../mold_cat_container.stl) | trial-01 で失敗 |
| v2: 自動生成クラムシェル型（上下分割） | [`mold_cat_clamshell_A.stl`](../../mold_cat_clamshell_A.stl) / [`mold_cat_clamshell_B.stl`](../../mold_cat_clamshell_B.stl) | trial-02 時点では未印刷 |

trial-02 では、設計し直した v2 クラムシェルがまだ印刷できていなかったので、
**v1 のコンテナ型 STL を [Bambu Studio](https://bambulab.com/ja/download/studio) のスライサーで左右に真っ二つにカット** して印刷するという workaround を採用。

```
v1 元データ          Bambu Studio で左右分割
   _______               ___    ___
  |       |             |   |  |   |
  |   🐱   |    →        | 🐱 ||🐱  |   (左右でミラーになる2片)
  |_______|             |___||___|
   ↑                     ↑
   底密閉で外せず         パーティング面で開く
```

つまり「クラムシェル化」は型を再設計せずに **スライサーのカット機能** で達成。
これにより v1 のメリット（既に印刷済の場合は不要）を活かしつつ離型問題を解消。

> 💡 設計した v2 自動生成クラムシェル（上下分割）は次回の検証課題として残っています。

---

### 使用したレシピ

| 材料 | 分量 |
|---|---|
| 重曹 | 70g |
| クエン酸 | 30g |
| 粗塩 | 20g |
| コーンスターチ | 10g |
| 精製水 | 約 15mL |

混ぜながら少しずつ水を加え、**「握ると固まり、つつくと崩れる」程度** を目安に湿度調整。
これを 4 色分（赤・緑・青・黄）それぞれ別ボウルで作成。

> 📚 **参考**: 篠原由子『バスボムレシピ — カラフル！シュワシュワ！身近な材料で
> 色も香りも自分だけのオリジナル』河出書房新社, 2015. ISBN 978-4309285597
> ([Amazon](https://www.amazon.co.jp/dp/4309285597))

---

### 香りのバリエーション

今回は 2 種類の香り付けを試しました:

1. **植物性オイル + ラベンダー精油** — 王道アロマ系
2. **「Princess ROSALINA」ボディースプレー（マリオ映画 × LUSH コラボ）** — グレープの香り

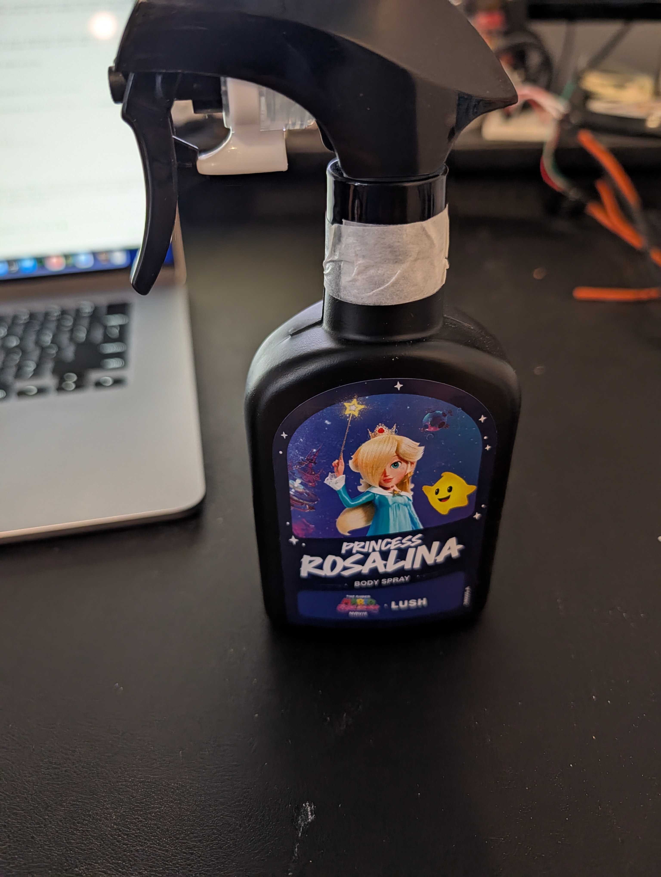
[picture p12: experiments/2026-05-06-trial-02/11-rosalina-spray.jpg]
ロゼッタ・ボディースプレー
   

   ギフト箱がマリオはてなブロックなので、香りもマリオ繋がりに。
   スプレータイプなので粉に直接吹き付けるだけで均一に香り付けできて便利でした。

---

### 制作手順（写真付き）

#### フェーズ A: 4 色の粉末準備

上記レシピを 4 つのボウルに分けて、それぞれ食用色素で **赤・緑・青・黄** に着色。
水とアルコール（or 香りスプレー）で湿度調整。

| | |
|---|---|
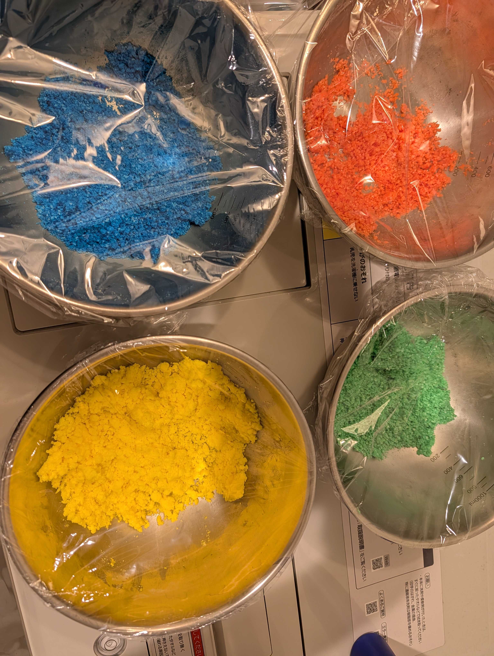
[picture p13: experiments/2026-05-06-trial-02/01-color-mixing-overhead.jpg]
色付き粉俯瞰
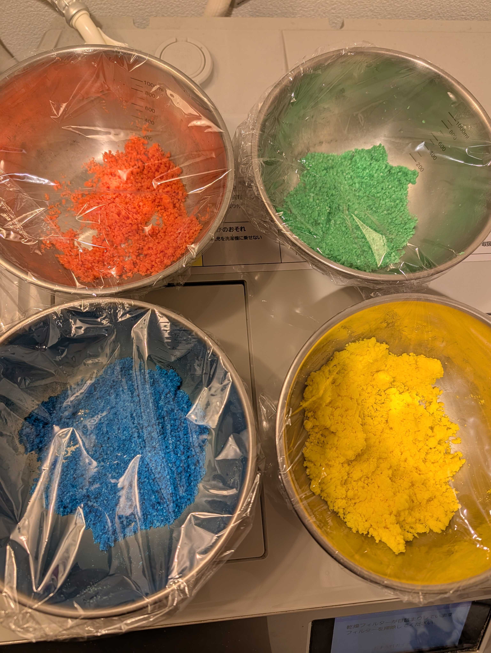
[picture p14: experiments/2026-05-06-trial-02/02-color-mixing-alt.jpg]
色付き粉別アングル
|  |  |

🎥 **混ぜている様子の動画**:

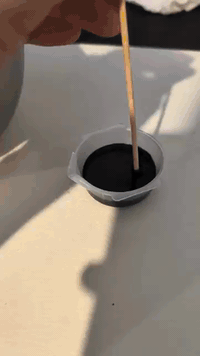
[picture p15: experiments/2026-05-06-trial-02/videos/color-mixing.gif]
色付き粉を混ぜている様子


> 👆 上はサイレントの GIF プレビューです（README 内で自動再生）。
> 音声付きの完全版は [YouTube Shorts](https://www.youtube.com/shorts/3kC7oP4pvtE) /
> または [`videos/color-mixing.mp4`](videos/color-mixing.mp4) を直接ダウンロード

ラップでボウルをカバーして粉の飛散と乾燥を防止。

#### フェーズ B: 型詰め・乾燥

左右分割した型の片方に粉を山盛りに詰め、もう片方をかぶせてぐっと押し付けて圧縮。
ゴムバンドで圧着して半日〜1 日乾燥。

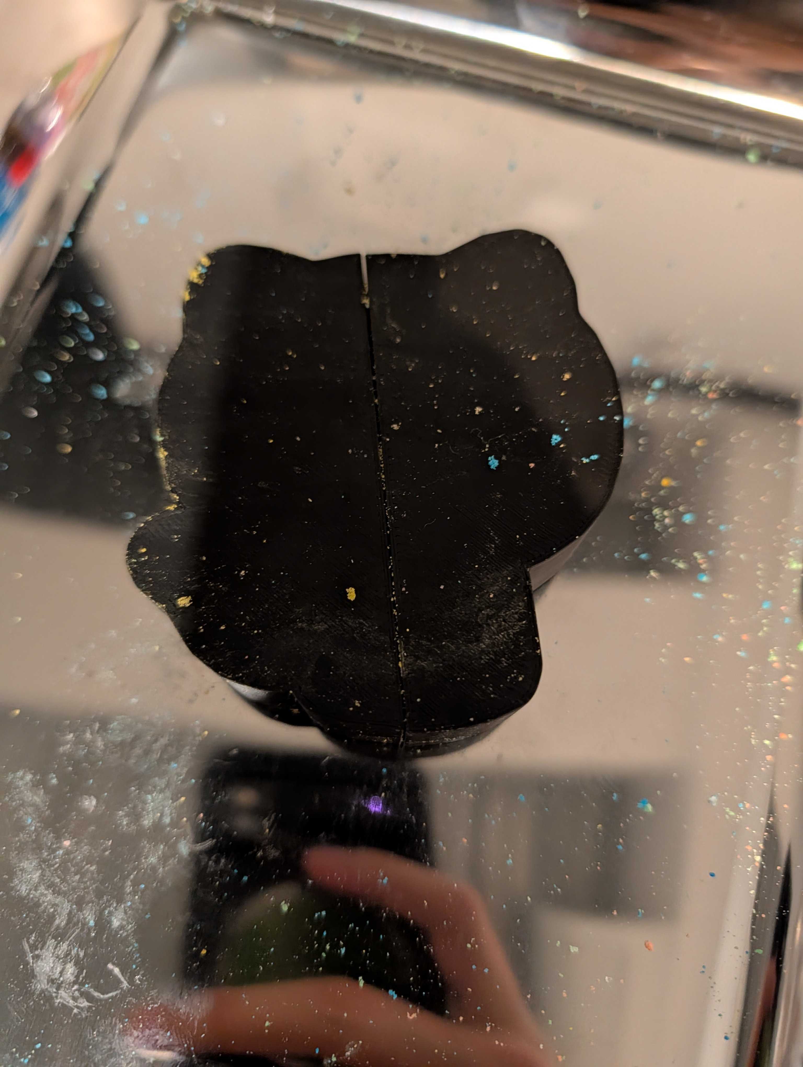
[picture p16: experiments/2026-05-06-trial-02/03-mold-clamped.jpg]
クランプされた型


#### フェーズ C: 離型 ⚠️ ここが一番繊細

乾燥後、ゴムバンドを外す。**ここからが Octocat 形状で一番デリケートな工程。**
「軽く叩けば外れる」みたいな単純な話ではないので、以下を守ってください。

##### 🚨 やってはいけないこと
- いきなり型を上下に引き剥がす → 耳・腕・触手が **ほぼ確実に折れます**
- 型を横方向にスライドさせる → 同じく崩壊します

##### ✅ 正しい「片面だけ」外し方
1. 型を背面（フラット側）にして机に置く
2. **腕がついている側の型半分を手でしっかり固定**
3. もう片方の型半分を **真上にゆっくり持ち上げる**
4. 顔と腕のあいだにある隙間を崩さないように沿わせるのがコツ

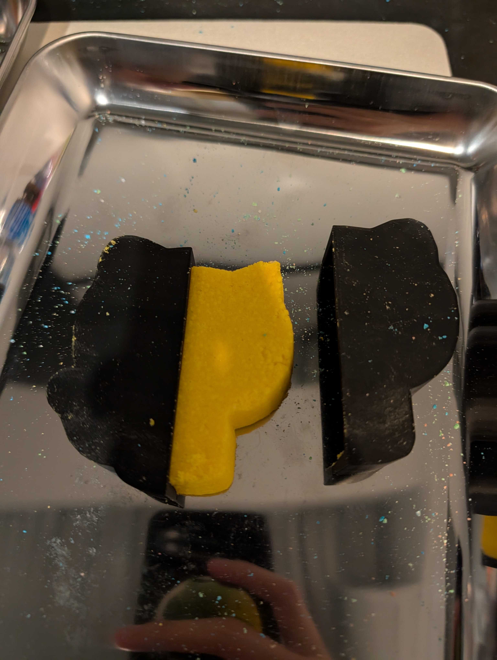
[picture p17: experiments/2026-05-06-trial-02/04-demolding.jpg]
型を開けた状態


うまく外れた成功例 ↓

成功した緑バスボム

##### 💡 そもそも完全に外さないという選択肢（個人的おすすめ）

片方を外せても、**もう片方の型を外すのが特に難しい**です。私は今回成功し
ましたが、人によっては高確率で崩れますし、誰かに渡すときに崩壊するのも
怖い。なので **「片方の型をつけたままお風呂に投入する」運用を強く推奨**
します。

これで問題ない理由:
- バスボムの表面のうち **半分以上は外気に露出している** ので、
  発泡反応に必要な水との接触面積は十二分にある（フェーズ F で実証済）
- 崩壊リスクがゼロ
- ギフトとして渡す場合、配送・手渡し時の破損も気にしなくていい
- **見た目もむしろこっちの方がカッコイイ**（次項）

##### 🎨 「型ごと」の方が見栄えが良い理由 — *Dragon Shading* との類似

型のフチが Octocat の輪郭をくっきり縁取って見えるため、いわゆる
**ドラゴンシェーディング**（セル／トゥーンシェーディングで強い黒輪郭線
を描く 3D アニメ表現の技法）と近い視覚効果が生まれます。

代表的な比較例:
- 『ドラゴンボール Z』(PS2) — 普通の 3D シェーディング
- 『ドラゴンボール Z2』(PS2) — キャラクターに **黒い輪郭線** が追加され、
  アニメ調・劇画調が一気に強まった

→ 今回のギフトは
**(a)** 贈呈時の崩壊リスクをゼロにする
**(b)** Octocat の輪郭がくっきり見えて見映えが良い
…という二重のメリットから、**あえて 4 個すべて型をつけたまま箱詰め**
しました。

#### フェーズ D: 保存・梱包

完成したバスボムは Ziploc に入れて湿気から保護。

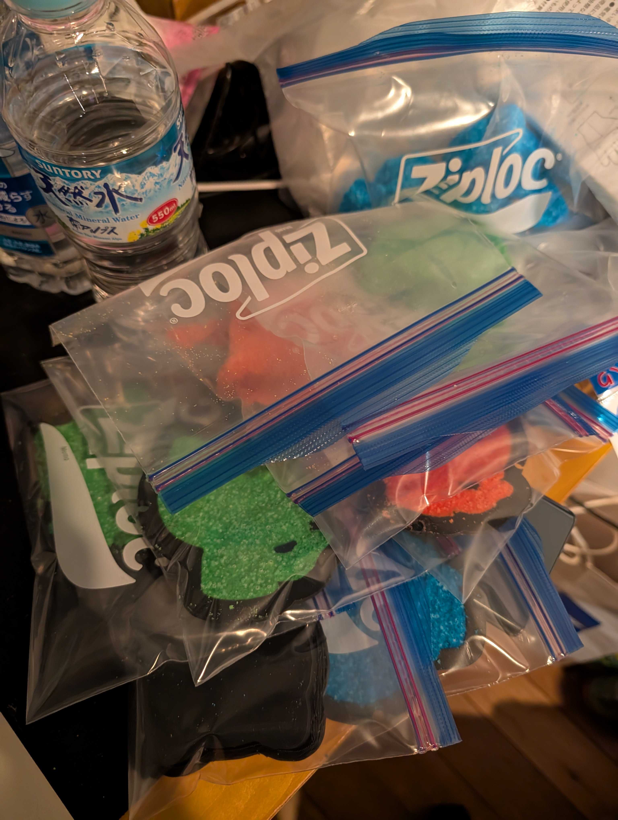
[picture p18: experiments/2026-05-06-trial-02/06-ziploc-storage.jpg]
Ziploc保存


緩衝材入りの白箱に 1 個ずつ、または 4 色セットで梱包（実際の贈呈は型ごと）。

| 1 個梱包 | 4 色セット |
|---|---|
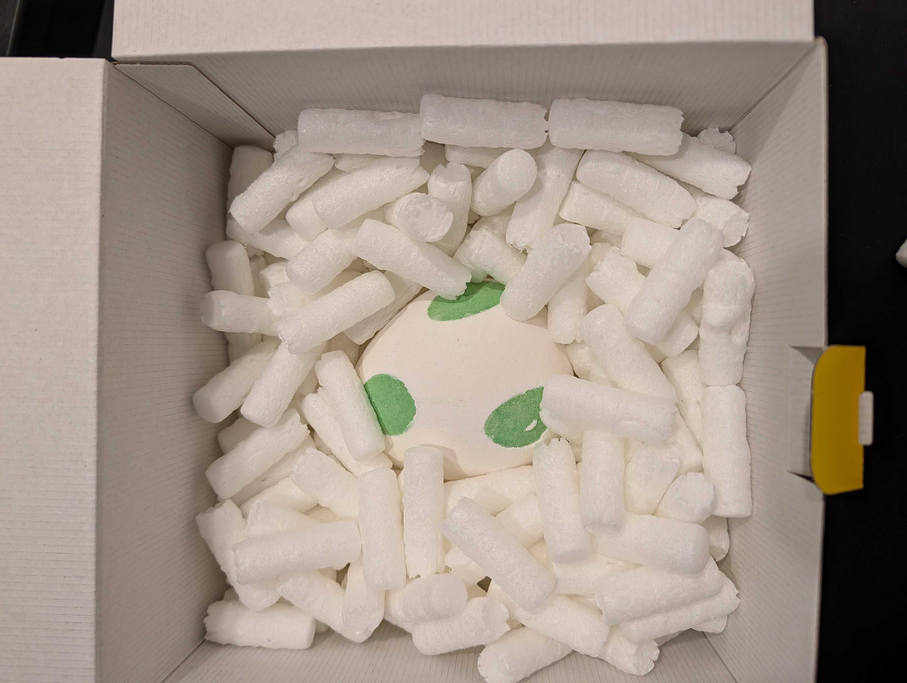
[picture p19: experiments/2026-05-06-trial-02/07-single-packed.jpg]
単品梱包
|  | 4色セット |

#### フェーズ E: ギフトラッピング 🎁

**Lush で買った期間限定の「マリオはてなブロック」型ギフトボックス**に詰めて、
ふたに Octocat ステッカーを貼って完成。
（ボックスは 3D プリント製ではなく既製品です。Mario × LUSH コラボの
期間限定商品として店頭に並んでいたものを購入しました）

| ブロック箱（前） | フタを閉じて完成 |
|---|---|
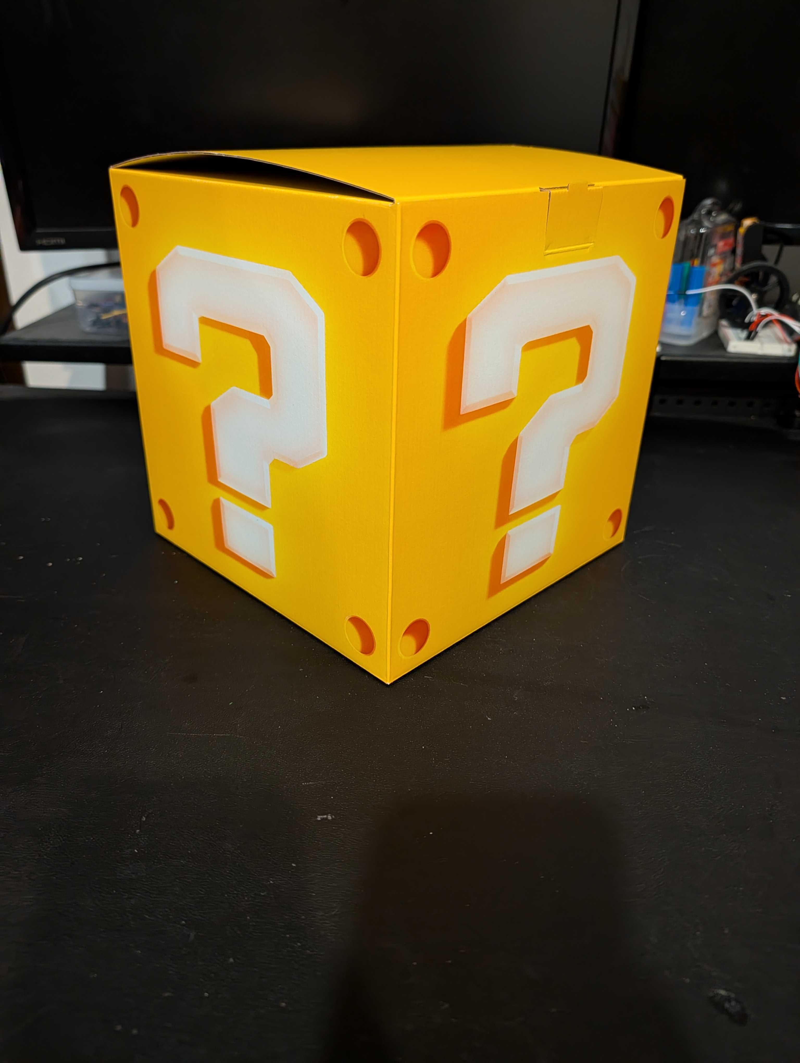
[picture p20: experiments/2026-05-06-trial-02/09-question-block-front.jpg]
はてなブロック箱・前面
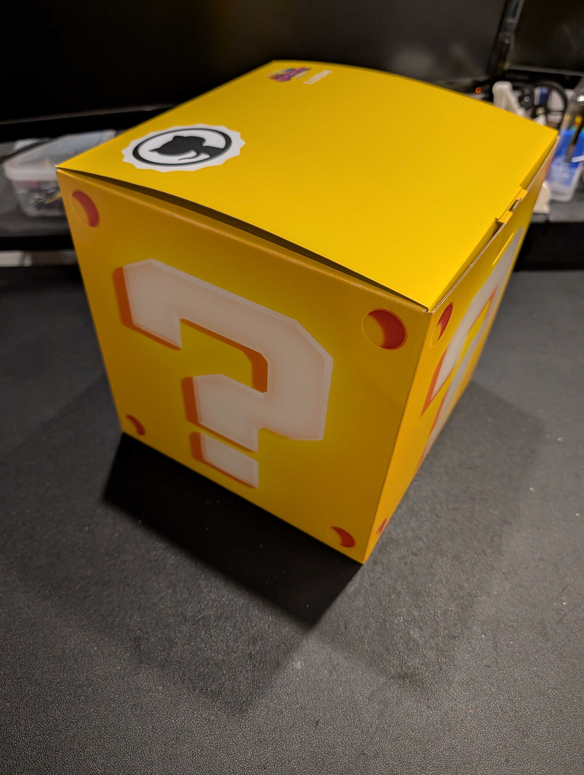
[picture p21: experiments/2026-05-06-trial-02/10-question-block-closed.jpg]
フタを閉じた完成形
|  |  |

#### フェーズ F: 機能テスト（実際にお湯に入れてみる）✅

形が崩れてしまったバスボム（離型ミスのプロトタイプ）を実際にお風呂に投入し、
**ちゃんとシュワシュワ反応するか** を検証。

🎥 **検証動画**:

お風呂で発泡している様子

> 👆 上は冒頭 20 秒のサイレント GIF プレビューです（README 内で自動再生）。
> 音声付き・全長 58 秒の完全版は [YouTube Shorts](https://www.youtube.com/shorts/VPH1sM8e9gE) /
> または [`videos/fizz-test.mp4`](videos/fizz-test.mp4) を直接ダウンロード

結果: **見た目が崩れていても化学反応は問題なく機能** ✨
重曹 + クエン酸 + 水 → 二酸化炭素の発泡反応はバスボムの形状とは無関係なので、
配送や手渡しで多少崩れても入浴剤としての性能には影響なし、ということが確認できました。

---

### Trial 01 → Trial 02 の変化

| 項目 | trial-01 | trial-02 | 結果 |
|---|---|---|---|
| 型 STL | `mold_cat_container.stl`（v1） | 同じ `mold_cat_container.stl` を使用 | — |
| 印刷方法 | そのまま 1 ピース印刷 | **Bambu Studio で左右 2 分割してから印刷** | ✅ パカッと外せる |
| 抜き勾配 | 5° | 5°（型は同じ） | ✅ 左右分割で 5° でも実用可 |
| ラップ | 直接詰め | 直接詰め（同じ） | — |
| 取り出し方 | 「外れない…」 | パカッ → 取り出せた | ✅ 離型成功（ただし脆さ問題で型ごと贈呈） |
| 配色 | 単色（赤） | 4 色（赤・緑・青・黄） | ✅ Microsoft ロゴ表現 |
| 香り | なし | ラベンダー / グレープ（ロゼッタ） | ✅ ギフト性 UP |

---

### 学び・気づき

- **スライサーのカット機能は強力**: 既存 STL を再設計せずに「クラムシェル化」可能
- **5° 勾配でも分割さえすれば離型可能** — v1 の失敗の主因は「床密閉」、勾配の浅さは二次要因だった
- **複数色の粉を別々に作る** ことで 1 セットで色違いの作品が作れる（Microsoft ロゴカラーや好きなテーマカラーで！）
- **乾燥は焦らない**：圧縮直後すぐ開けると崩れるリスク。ゴムバンドで半日以上クランプ推奨
- **細部のあるシルエットは脆い**：Octocat の耳や触手のような細い部分は離型できても、配送・手渡しの振動で欠けやすい。ギフト用は **「型に詰めたまま渡す」のが安全**（型もギフトの一部に！）
- **香り付けはスプレーが楽**: 既製のボディースプレーを使えば均一・お手軽
- **保険は大事**: 自作の出来に自信が無ければ市販品も同梱するのは賢いリスクヘッジ

---

### 参考文献

- 📖 篠原由子『バスボムレシピ — カラフル！シュワシュワ！身近な材料で色も香りも自分だけのオリジナル』河出書房新社, 2015. ISBN 978-4309285597 — [Amazon](https://www.amazon.co.jp/dp/4309285597) / [版元ドットコム](https://www.hanmoto.com/bd/isbn/9784309285597)
  - 100 円ショップで揃う材料でカラフルなバスボムを作るレシピ集。今回の配合の出発点として参照。
- 🛠️ [Bambu Studio](https://bambulab.com/ja/download/studio) — STL を左右分割するために使用したスライサー

---

## English

Second trial — **four-color Octocat bath bombs!** 🐱✨

This trial built on the lessons from [Trial 01 (failure)](../2026-05-04-trial-01/), but the
**actual fix was different from what we'd designed** (see "Mold used" below).

> 📌 **Caveat**: Although demolding worked, the thin **ears and tentacles** of the Octocat
> shape turned out to be fragile and tended to crumble during handling. So for the actual
> gift we **left the bath bombs inside their molds** — the recipient simply opens the
> mold and drops the bath bomb directly into the bath. As a bonus, the 3D-printed mold
> becomes part of the gift 🎁

---

### Backstory 🎁

These bath bombs were made as a farewell gift for **a colleague leaving GitHub
(formerly at Microsoft)**. To honor both employers, four Octocats were cast in the
**Microsoft logo colors (red, green, blue, yellow)** and packed into a
**Mario "question-block" gift box found as a Lush limited-edition item**.

> 💡 While picking up the question-block box at **Lush**, we also bought a
> Lush "Yoshi's Egg" bath bomb and a foam bath bomb as a backup — insurance
> in case the homemade ones turned out badly. They didn't, so both the
> homemade and the Lush bath bombs went into the final gift.

---

### Mold Used — design vs. reality

This repo contains **two** mold STLs:

| Mold | Files | Status |
|---|---|---|
| v1: single-sided container | [`mold_cat_container.stl`](../../mold_cat_container.stl) | failed in trial-01 |
| v2: auto-generated clamshell (top/bottom split) | [`mold_cat_clamshell_A.stl`](../../mold_cat_clamshell_A.stl) / [`mold_cat_clamshell_B.stl`](../../mold_cat_clamshell_B.stl) | not yet printed at trial-02 time |

For trial-02 the redesigned v2 clamshell wasn't printed yet, so we used a **workaround**:
take the v1 container STL and **split it left/right in [Bambu Studio](https://bambulab.com/en/download/studio)'s slicer** before printing.

```
v1 model            Split L/R in Bambu Studio
   _______               ___    ___
  |       |             |   |  |   |
  |   🐱   |    →        | 🐱 || 🐱 |   (mirrored left + right pieces)
  |_______|             |___||___|
   ↑                     ↑
   sealed floor          opens at parting plane
```

So "clamshell-ification" was achieved via the **slicer's cut function** instead of a redesign.
The auto-generated v2 clamshell mold remains a future task to validate.

---

### Recipe used

| Ingredient | Amount |
|---|---|
| Baking soda | 70g |
| Citric acid | 30g |
| Coarse salt | 20g |
| Cornstarch | 10g |
| Purified water | ≈15mL |

Mix and add water gradually until the powder **clumps when squeezed but crumbles when poked**.
Make 4 separate batches (red, green, blue, yellow).

> 📚 **Recipe reference**: Yuko Shinohara, *Bath Bomb Recipes — Colorful & Fizzy:
> Make Your Own Originals from Common Ingredients* (バスボムレシピ),
> Kawade Shobo Shinsha, 2015. ISBN 978-4309285597 (Japanese only) —
> [Amazon (Japan)](https://www.amazon.co.jp/dp/4309285597)

---

### Fragrance variations

We tried two scenting approaches:

1. **Plant-based oil + lavender essential oil** — classic aromatherapy approach
2. **"Princess ROSALINA" body spray (Mario Movie × LUSH collab)** — grape scent

   Rosalina body spray

   Since the gift box was a Mario question block, we matched the fragrance to the
   theme. The spray format made it easy to evenly scent the powder.

---

### Process (with photos)

#### Phase A — Mix four colors of powder

Split the recipe into four bowls and tint each with food coloring
(**red, green, blue, yellow**). Adjust hydration with water and the optional
fragrance spray.

| | |
|---|---|
| Powders, overhead | Powders, alt angle |

🎥 **Video of the mixing**:

Mixing colored bath bomb powders

> 👆 The above is a silent GIF preview that plays inline in the README.
> For the full version with audio, see [YouTube Shorts](https://www.youtube.com/shorts/3kC7oP4pvtE)
> or download [`videos/color-mixing.mp4`](videos/color-mixing.mp4) directly.

Plastic wrap kept the bowls dust-free and dry until packing.

#### Phase B — Pack the mold

Heap each color into one half of the slicer-split mold, press the other half down firmly,
clamp with rubber bands, and leave to cure for half a day to a full day.

Clamped mold

#### Phase C — Release ⚠️ The most delicate step

After curing, remove the rubber bands. **This is the most fragile step
when the bath bomb is shaped like an Octocat** — it's not just "tap and
pop", so please follow the rules below.

##### 🚨 What NOT to do
- Pull the two halves apart abruptly → ears, arms and tentacles will
  **almost certainly snap off**
- Slide the mold halves sideways → same result, total collapse

##### ✅ Correct way to release one half
1. Lay the mold flat on its back (flat side down)
2. **Hold the half containing the arms firmly in place** with one hand
3. **Lift the other half straight up, slowly**, keeping it perfectly vertical
4. The trick is to follow the natural gap between the face and the arms
   without disturbing it

Mold opened

A successful release looks like this ↓

Successful green Octocat

##### 💡 Or just don't fully demold (my personal recommendation)

Even after one half comes off, removing **the second half is genuinely
hard**. I succeeded this time, but many people will crumble it; and even
if you succeed, it could still break in transit when handing it to
someone. So I strongly recommend **leaving one mold half attached and
dropping the whole thing into the bath as-is**.

Why this is fine:
- More than half of the bath bomb's surface is already exposed to air,
  so the contact area with bath water is more than sufficient for a
  proper fizz reaction (verified in Phase F below)
- Zero crumbling risk
- Zero damage risk during gift transit / handover
- **It actually looks cooler this way too** (next note)

##### 🎨 Why the "in-mold" look is more visually appealing — *Dragon Shading* analogy

The edge of the mold traces a clean outline around the Octocat
silhouette, producing the same kind of visual effect as the
**"Dragon shading"** technique — i.e. cel/toon shading with bold black
outlines drawn on top of an otherwise 3D character.

Reference comparison:
- *Dragon Ball Z* (PS2) — standard 3D shading
- *Dragon Ball Z2* (PS2) — characters now have **bold black outlines**,
  making them look much more anime-/comic-styled

→ For this gift, leaving the mold attached gave us
**(a)** zero crumbling risk in transit, and
**(b)** a sharper, more iconic Octocat silhouette
…so all four bath bombs were boxed up still snugly inside their molds.

#### Phase D — Store & pack

Each bath bomb went into a Ziploc bag to protect against humidity.

Ziploc storage

Either packed individually or as a 4-color set in a white box with peanut packing
(though the actual gift kept the bath bombs inside their molds).

| Single | Set of four |
|---|---|
| Single packed | Set of four |

#### Phase E — Gift wrapping 🎁

The set was placed inside the **Mario "question-block" gift box bought at Lush**
(a Mario × LUSH limited-edition item — *not* 3D printed) with an Octocat sticker
on the lid.

| Block (front view) | Final lid closed |
|---|---|
| Question block, front | Question block, closed |

#### Phase F — Functional test (drop one in the bath) ✅

We dropped a misshapen prototype (a demolding failure) into actual bath water to check
whether **the fizz reaction still worked** despite the broken shape.

🎥 **Test video**:

Bath bomb fizzing in actual bath water

> 👆 The above is a silent GIF preview of the first 20 seconds, which plays
> inline in the README. The full 58-second version with audio is on
> [YouTube Shorts](https://www.youtube.com/shorts/VPH1sM8e9gE)
> or downloadable as [`videos/fizz-test.mp4`](videos/fizz-test.mp4).

Result: **the chemistry works fine even when the bath bomb is cosmetically broken** ✨
Baking soda + citric acid + water → CO₂ fizz is independent of the bath bomb's shape,
so even if a bath bomb crumbles in transit it will still perform its intended function
in the tub.

---

### Trial 01 → Trial 02 differences

| Item | Trial 01 | Trial 02 | Result |
|---|---|---|---|
| Mold STL | `mold_cat_container.stl` (v1) | Same `mold_cat_container.stl` | — |
| Print method | Whole, single piece | **Sliced L/R in Bambu Studio first** | ✅ Opens cleanly |
| Draft angle | 5° | 5° (same mold) | ✅ 5° is OK once split |
| Liner | None | None (same) | — |
| Removal | "Won't come out…" | Pop → Out | ✅ Demolds OK (gifted in-mold due to fragility) |
| Colors | Single (red) | Four (red, green, blue, yellow) | ✅ Microsoft logo theme |
| Scent | None | Lavender / grape (Rosalina spray) | ✅ Better gift |

---

### Lessons Learned

- **Slicer cut functions are powerful**: You can "clamshell-ify" any solid mold STL
  in your slicer without redesigning the model.
- **5° draft is workable as long as you can split the mold** — trial-01's main failure
  was the *sealed floor*, not the shallow draft.
- **Mix multiple colors separately** to make a multi-color set in a single mold —
  great for themed gifts.
- **Don't rush the cure.** Opening too soon risks crumbling. Half a day under rubber-band clamp is the minimum.
- **Detailed silhouettes are fragile.** Thin features like Octocat ears and tentacles
  release from the mold OK but tend to chip during transit and handling. For gifts,
  **leaving the bath bomb inside the mold is safer** (the mold becomes part of the gift).
- **Pre-made body sprays make scenting easy.** No need to fuss with essential oils.
- **Insurance pays.** Including a commercial bath bomb as backup is a smart hedge for first-time gifts.

---

### References

- 📖 Yuko Shinohara, *バスボムレシピ — カラフル！シュワシュワ！身近な材料で色も香りも自分だけのオリジナル*
  (Bath Bomb Recipes — Colorful & Fizzy), Kawade Shobo Shinsha, 2015.
  ISBN 978-4309285597 (Japanese only) —
  [Amazon (Japan)](https://www.amazon.co.jp/dp/4309285597) /
  [Hanmoto.com](https://www.hanmoto.com/bd/isbn/9784309285597)
  - The starting point for our recipe ratios.
- 🛠️ [Bambu Studio](https://bambulab.com/en/download/studio) — slicer used for the L/R split print

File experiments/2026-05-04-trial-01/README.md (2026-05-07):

# 🧪 Trial 01 — 2026-05-04（失敗）

第1回試作の記録。**バスボムが型から取り出せず失敗**。型のデザインを根本から見直すきっかけとなった試行。

> ✅ **続きあり**: ここで得た学びを反映して再設計した結果、[Trial 02](../2026-05-06-trial-02/) で成功しました 🎉

---

## 使用した型

| 項目 | 値 |
|---|----|
| STLファイル | [`mold_cat_container.stl`](../../mold_cat_container.stl) |
| 型方式 | 片面コンテナ型（床密閉・上面開口） |
| キャビティ深さ | 25mm |
| 抜き勾配 | 5° |
| 壁厚 / 床厚 | 4mm / 4mm |
| フィレット | R3mm |
| プリント材料 | PLA |

## 制作手順（実施したもの）

1. 重曹・クエン酸・コーンスターチを計量・混合
2. 食用色素（赤）で着色
3. 無水エタノールで湿度調整
4. 型に詰めて上面を平らにならす
5. 数時間〜半日乾燥させた後、型から外そうとした

## 失敗の状況

- 型をひっくり返しても、押しても、バスボムが**全く外れなかった**
- ラップを敷かずに直接詰めたため、型内壁との密着が強かった可能性あり
- 上面（型から見える面）はそれなりに綺麗に固まっていた

📷 失敗時の写真:

| 段階 | 画像 |
|---|---|
| 材料準備 | materials |
| 粉末混合中 | mixing |
| 型から外せず詰まったまま | stuck |

## 失敗の根本原因（分析）

| # | 原因 | 説明 |
|---|---|---|
| 1 | **床密閉のコンテナ構造** | 底から押し出す手段がなく、ひっくり返して落とすしかない構造 |
| 2 | **抜き勾配5°が浅い** | 粉末・もろい材料には10°前後が必要。FDMの層間スジによる摩擦も加味されていなかった |
| 3 | **複雑なシルエット** | 猫の耳・触手の凹凸が多く、ラップを綺麗に敷くのが現実的に困難 |
| 4 | **離型剤・ラップ未使用** | 直接詰めたため内壁との密着が強かった |

## 次回への改善方針

→ 型を **クラムシェル2分割型** に再設計する（[../../README.md](../../README.md) 参照）。

主なポイント:
- 左右対称の半身がパーティングプレーンで合わさる構造に変更
- 抜き勾配を 5° → 8° に拡大
- 周囲フランジ + 位置決めピンで自己整合
- 取り出しは「パカッと開ける」だけ

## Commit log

2026-04-11 🛁 GitHub Octocat バスボム型の自動生成スクリプト
    画像からOctocat形状を抽出し、3Dプリント用モールドSTLを生成する。
    3種類の型（シルエット/レリーフ/くり抜き）× 上下型 = 計6ファイル。
2026-04-11 🐱 猫シルエットのみ抽出（外周リング除去）
    画像処理を改善:
    - 距離ヒストグラム分析で猫本体とアンチエイリアスリングを分離
    - フラッドフィル成長で猫の凹部も正確に抽出
    - 切断された触手パーツを自動検出・追加
    - 型サイズ: 134×134mm → 85×91mm（猫フィギュア型）
    [preview_bathbomb_shape.stl]
2026-04-12 🐱 猫型コンテナモールドに変更（片面型）
    - 四角ブロック+穴 → 猫シルエットに沿った容器型に変更
    - 壁3mm・床3mm・深さ25mm
    - 底面完全密閉、上面のみ開口（材料投入口）
    - 不要な2つ割り型・デバッグ画像を削除
    [preview_bathbomb_shape.stl]
2026-04-12 🔧 猫型コンテナモールドに全面改善
    - 抜き勾配5°（底が狭く上が広い → 取り出しやすい）
    - フィレットR3mm（全角を丸めてひび割れ防止）
    - 壁厚4mm・床厚4mm（たわみ防止）
    - 写真90x55mmが入るようキャビティ調整
    - スクリプトをシンプルな片面型専用に書き直し
2026-04-12 📖 完全制作ガイド追加（買い出し〜ラッピングまで）
2026-04-12 🌐 日英切り替え対応（README + GUIDE_EN.md）
    - README.md: 日本語/English セクション切り替え
    - GUIDE_EN.md: 英語版完全制作ガイド追加
    - GUIDE.md: 日本語版（既存）
2026-04-12 Add generated STL file and remove STL exclusion from .gitignore
    - Remove mold_*.stl from .gitignore so STL files are tracked
    - Add mold_cat_container.stl (cat-shaped container mold)
    [mold_cat_container.stl]
2026-04-12 🐱 STLファイルをリポジトリに追加（通常+反転）
    - mold_cat_container.stl — 通常版
    - mold_cat_container_mirrored.stl — 左右反転版（取り出し後の向き補正）
    - .gitignore からSTL除外ルールを削除
    [mold_cat_container_mirrored.stl]
2026-05-04 🧪 Add trial-01 failure log (mold release issue)
    First trial used the single-sided cat container mold but the bath bomb
    could not be released from the cavity. Adds photos and root-cause analysis
    under experiments/2026-05-04-trial-01/ for future reference.
2026-05-04 🐱 Redesign mold as 2-piece clamshell + drop photo-surprise feature
    After trial-01 showed the single-sided container mold makes the bath bomb
    impossible to release, redesign as a clamshell (halves A and B) so the
    finished bath bomb pops out cleanly when the halves are unclipped.
    Changes to generate_mold.py:
    - New build_half(cat_poly, side) producing two mirrored halves
    - Side A has 4 alignment pins; side B has matching holes (PIN_CLEARANCE 0.3mm)
    - 5mm outer flange around the parting plane (rubber-band clamp surface)
    - Draft increased 5° -> 8° for easier release of powdery material
    - Cavity depth 25mm -> 20mm per half (40mm total bath bomb)
    - Removed PHOTO_LONG/PHOTO_SHORT c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
    [mold_cat_clamshell_A.stl, mold_cat_clamshell_B.stl]
2026-05-04 📖 Update guide for clamshell mold + remove photo-surprise feature
    Updates README.md, GUIDE.md, and GUIDE_EN.md (JA + EN) to reflect the
    new clamshell mold design:
    - Reference new STL pair (mold_cat_clamshell_A/B.stl) and note that
    the original mold_cat_container*.stl files are kept as historical
    artefact, with link to experiments/2026-05-04-trial-01/
    - Updated mold spec tables (8° draft, flange, dowels, target width)
    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
2026-05-04 📏 Halve clamshell mold thickness (20mm -> 10mm per half)
    The previous 40mm-total bath bomb felt too large in hand. Reducing
    DEPTH_HALF from 20mm to 10mm gives a ~20mm-total flatter bath bomb
    that's closer to typical commercial bath bomb sizes while keeping
    the same 80mm cat silhouette.
    Effects:
    - Half body height: 24mm -> 14mm (B), 30mm -> 20mm (A with pins)
    - Outer footprint: 98x104mm -> 96x101mm (smaller draft offset)
    - Print time roughly halved (4-6h -> 2-3h)
    - Updated README spec table and GUIDE schedule
    [mold_cat_clamshell_A.stl, mold_cat_clamshell_B.stl]
2026-05-04 🔩 Loosen pin-hole clearance (0.3mm -> 0.8mm radial)
    Trial fit revealed the alignment holes were too tight to fit over the
    pins after FDM shrinkage. Increasing PIN_CLEARANCE from 0.3mm to 0.8mm
    per radius makes the hole 5.6mm dia (was 4.6mm) for the 4mm pins,
    giving a generous slip fit that should accommodate typical FDM
    hole-shrinkage of 0.2-0.4mm and still align reliably.
    Pin diameter / length and flange geometry are unchanged.
    [mold_cat_clamshell_B.stl]
2026-05-04 Fix clamshell halves A/B not mating (mirror cat for B)
    Half B is flipped in X when mated to half A. Without pre-mirroring the
    cat profile for B, the asymmetric Octocat cavity and the alignment pin
    positions did not register, leaving the two halves unable to close.
    Pre-mirror cat_poly in X before passing to build_half(side='B').
    Verified: all 4 pin/hole pairs align with 0.00 mm offset after mating.
    Fixes #1
    [mold_cat_clamshell_A.stl, mold_cat_clamshell_B.stl]
2026-05-07 🎉 Add Trial 02 success log with 4-color Octocat photos
    Documented the second trial which was a complete success:
    - All 10 photos copied to experiments/2026-05-06-trial-02/ with
    descriptive names (process: 01-05, packaging/gift: 06-10)
    - Bilingual (JA + EN) success log written matching trial-01's format
    Story: Made as a farewell gift for a colleague leaving GitHub
    (formerly at Microsoft) — cast in the Microsoft logo colors
    (red/green/blue/yellow) and packed in a 3D-printed Mario question
    block box, with a Lush Yoshi Egg bath bomb included as backup.
    Every 'next-trial' improvement item from trial-01 was achieved:
    clamshell vs container, 8 vs 5 deg draft, halved thickness, loose
    pin cl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
2026-05-07 📝 Trial-02: corrections, recipe, fragrances, videos & references
    Major rewrite of the trial-02 success log to reflect what actually
    happened and add the details the maker provided afterward:
    * Mold approach: trial-02 did NOT use the new auto-generated v2
    clamshell mold. Instead the original v1 mold_cat_container.stl
    was sliced left/right in Bambu Studio's slicer before printing
    — a workaround that solved the demolding issue without redesign.
    Documented this honestly with a diagram and updated the comparison
    table accordingly.
    * Recipe table added (baking soda 70g / citric acid 30g /
    coarse salt 20g / cornstarch 10g / water ~15mL, mix until 'clumps
    when squeezed, crumbles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
2026-05-07 📸 Add static STL previews to work around GitHub's flaky 3D viewer
    GitHub's inline STL viewer shows 'Unable to render code block' for
    the mold STLs in this repo, so add a generate_previews.py script
    that renders top-down PNG previews of every STL using trimesh +
    matplotlib (headless, no GPU required). The PNGs are checked into
    previews/ and embedded in the main README in both JA and EN
    sections, with a callout pointing readers to ViewSTL or a local
    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
2026-05-07 🎨 Trial-02 Phase C: detailed demolding tips + 'in-mold' rationale
    Phase C was the trickiest step in trial-02 and the original write-up
    glossed over it. Expand both JA and EN sections with:
    - ⚠️ What NOT to do
    - Don't yank the two halves apart — fragile parts (ears, arms,
    tentacles) will snap off
    - Don't slide sideways — same result
    - ✅ Correct one-half release
    - Lay flat on the back side
    - Hold the half with the arms still
    - Lift the other half straight up, slowly
    - Follow the natural gap between face and arms
    - 💡 'Or just don't fully demold' — recommended option
    - Removing the second half is genuinely hard for most people
    - Surface area exposed is al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
2026-05-07 🎁 Trial-02 fact-fix + inline video playback
    Two factual corrections + presentation upgrade.
    == Fact-fix: Mario question-block box was NOT 3D printed ==
    It was bought as a Mario × LUSH limited-edition item at Lush.
    While picking up the box at the same Lush store, a 'Yoshi's Egg'
    bath bomb and a foam bath bomb were also purchased and included
    as backup gifts (in case the homemade ones failed). They didn't
    fail, so both the homemade and Lush bath bombs went into the
    final gift.
    Updated mentions in:
    - Main README JA Success Story section
    - Main README EN Success Story section
    - experiments/2026-05-06-trial-02/README.md JA backstory + Phase E
    - experiments/2026-05-06-trial-02/README.md EN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
2026-05-07 🎬 Use absolute github.com raw URLs in <video> src
    Relative-path <video src='videos/...mp4'> tags were being stripped by
    GitHub's markdown HTML sanitizer (rendered as empty <p></p>). Switching
    to absolute https://github.com/USER/REPO/raw/refs/heads/main/... URLs
    should pass the sanitizer's allowlist while still streaming the same
    MP4 from the repo.
2026-05-07 🎞️ Inline GIF previews instead of stripped <video> tags
    Investigation: GitHub's README markdown renderer strips <video> tags
    entirely (verified via /api/v3/repos/.../contents/...md with Accept:
    application/vnd.github.html — both relative and absolute github.com
    raw URLs produced empty <p></p> in the rendered DOM).
    Workaround: convert each MP4 to an autoplaying silent GIF (the only
    type of moving image GitHub README will actually play inline) and
    The original full-quality MP4 + the YouTube Shorts URL stay as
    fallback links right under the GIF, for users who want audio or
    the longer cut.
    Files added:
    - experiments/2026-05-06-trial-02/videos/color-mixing.gif (2.8 MB,
    full 11.7 s @ 20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
2026-05-07 📘 Add GitHub Pages demolding guide (Google Codelab style)
    New docs/ tree publishes a step-by-step demolding walkthrough modeled
    on the Google Codelab Elements design (same look & feel as
    https://moulongzhang.github.io/2025-Github-Copilot-Workshop/).
    Architecture (mirrors reference site):
    - docs/index.html — version-selector + iframe wrapper
    Reads ?version=... query param, syncs hash through to inner iframe,
    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
2026-05-07 docs: add English codelab + language toggle + themed Octocats
    What's new
    ----------
    * English version of the demolding guide:
    docs/versions/v1.0.0/index_en.html (full 8-step translation,
    same structure and tone as JA, with Octocat decorations).
    * Language selector in the wrapper (docs/index.html):
    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
